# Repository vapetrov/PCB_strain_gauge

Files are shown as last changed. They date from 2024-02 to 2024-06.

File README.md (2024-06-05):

# PCB Strain Gauge

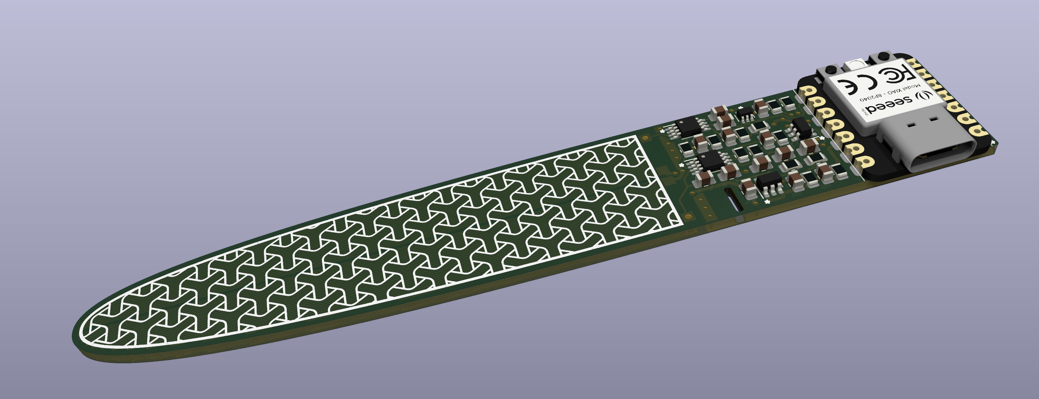
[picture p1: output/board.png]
board


A strain gauge, with amplifier, where the sensing element is the circuit board itself. Sensitive enough to measure deflections in the range of micrometers while having a full scale deflection range of +/- 3cm.

https://github.com/vapetrov/PCB_strain_gauge/assets/7529600/8c5e6594-8a19-4efe-8d25-b016dfba4ef4

### [View files with KiCanvas!](https://kicanvas.org/?github=https%3A%2F%2Fgithub.com%2Fvapetrov%2FPCB_strain_gauge)

## Manufacturing
The recommended board thickness is 0.6mm, although it could be made thicker or thinner for different applications. Thinner boards will result in a smaller output voltage swing.

- strain_gauge_3.zip
    - 20 mm x 118 mm, 2 layer
    - 0.15mm (~6mil) min trace width
    - 4-element sensing bridge
- strain_gauge_3_rotated.zip
    - Same as the previous one, except it uses 2-element sensing.
    - Lower thermal drift and bias from manufacturing (theoretically)
- stran_gauge_stiffener.zip
    - 20 mm x 42 mm rectangle to keep the component side from flexing
    - Can be affixed to the board with 3M VHB 5906

## Assembly
This project was made with hand-assembly in mind, and does not require hot air or a reflow oven.

The board can be used standalone with an integrated microcontroller (Seeed Studio XIAO RP2040) or an external microcontroller through the header pins.  
The external ADC (U5) can be omitted, and the analog voltage can be sampled directly on the "OUT" pin.  
The bias voltage generator (U8, U4) can also be omitted by placing a jumper wire between pins 2&3 on U8. Doing this will result in a measureable voltage on the output when no force is applied. 

## Programming

The included sample firmware will wait until a serial console is opened, perform a 5 second offset calibration, then sample continuously at the lowest gain setting. The `graph.py` script can be used to display the output.  
For high sensitivity measurements, it's important to let the board reach a stable operating temperature for at least 5 minutes before calibrating.

## Customatization

To customize the shape of the sensing element, `draw_footprint.ipynb` can be used to generate an outline of a given width, height and curvature. The resulting `.svg` can be imported into Inkscape and converted into a KiCad footprint using the [svg2shenzen](https://github.com/badgeek/svg2shenzhen) tool.

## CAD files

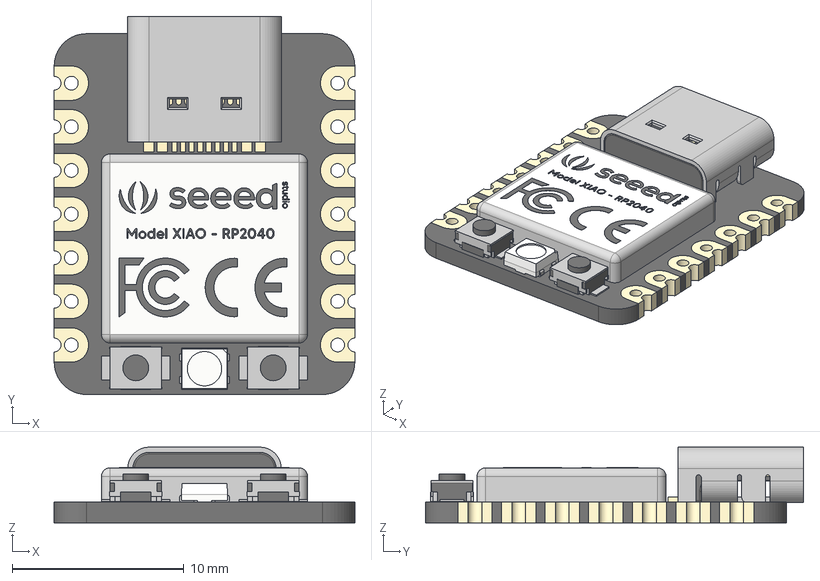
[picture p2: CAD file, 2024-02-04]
3D/Seeed Studio XIAO RP2040 v26.step
17.5 x 22.0 x 4.40 mm
type-c v2
smd_button v3
DOUT
DIN
VSS
VDD
smd_button v3(Mirror)

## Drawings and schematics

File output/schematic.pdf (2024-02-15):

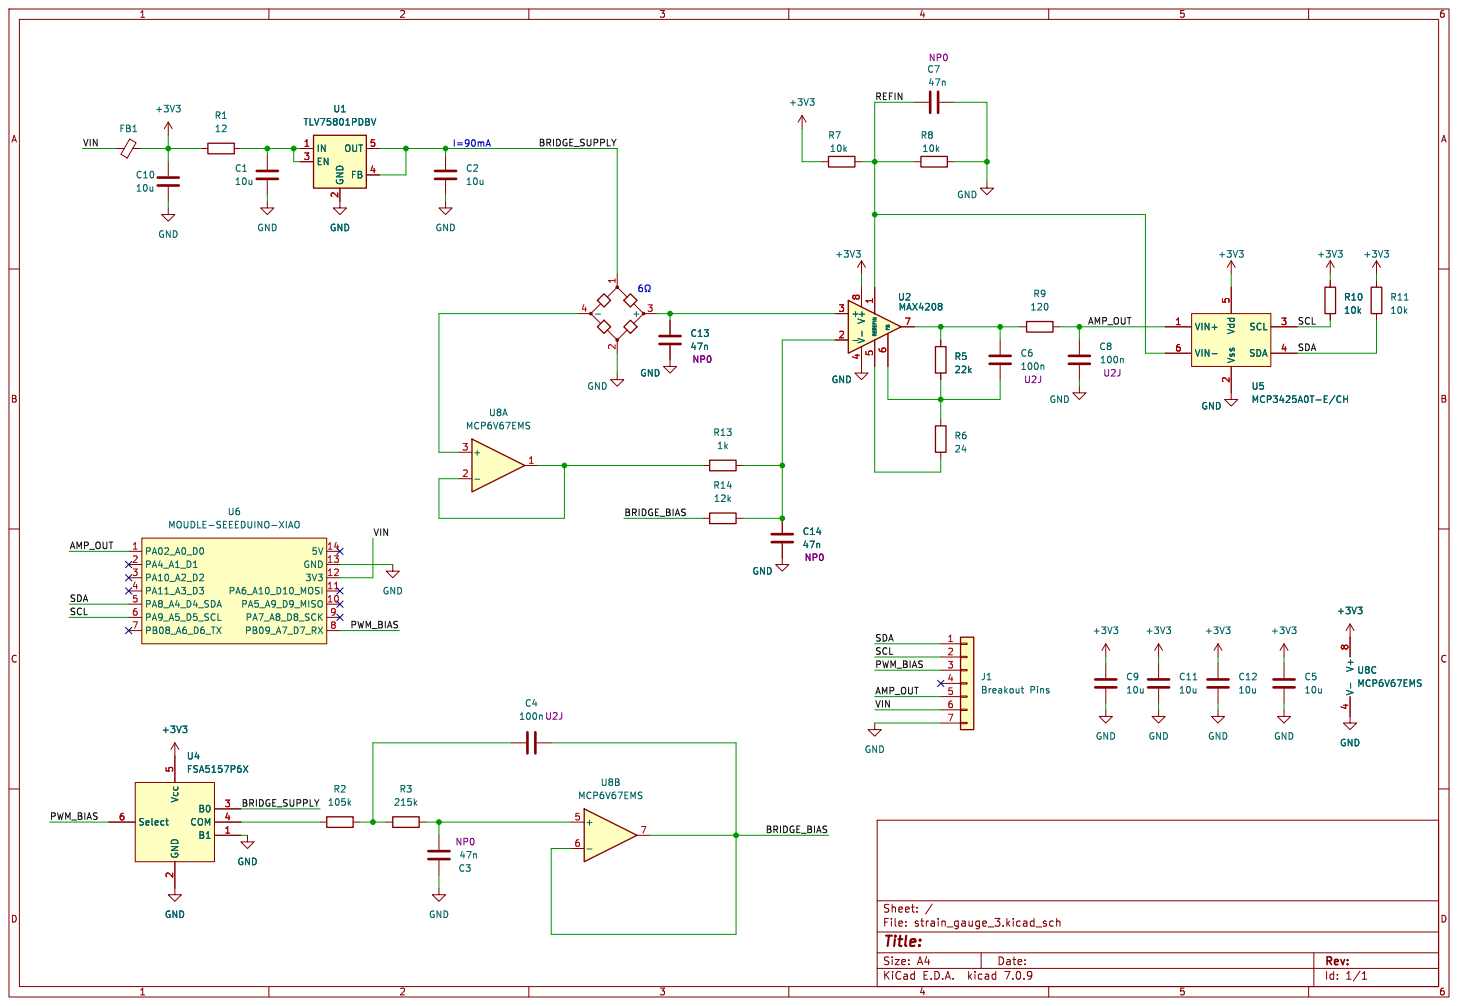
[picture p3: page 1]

2 EN 3 FB 4 OUT 5 U1 TLV75801PDBV GND

2 B0 3 COM 4 Vcc 5 Select 6 R5 GND 22k C13

Id: 1/1 Title: File: strain_gauge_3.kicad_sch Sheet: /

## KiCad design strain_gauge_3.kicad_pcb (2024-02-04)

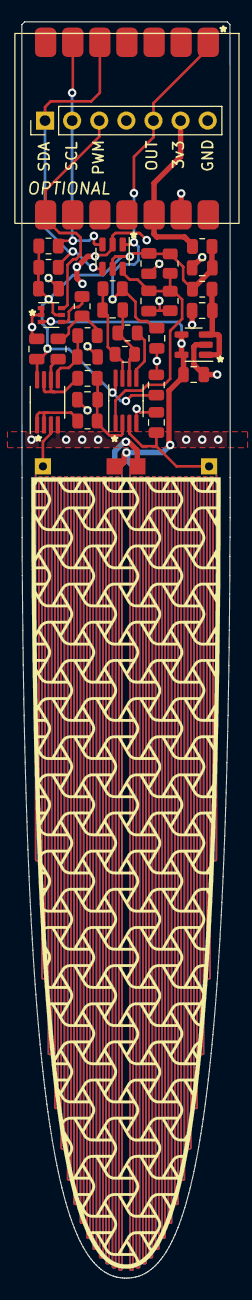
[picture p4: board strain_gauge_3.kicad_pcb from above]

Board: 2 copper layers, 19.5 x 117.7 mm, 37 parts (0 on the bottom side), 21 nets.

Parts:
C1, C2, C5, C9, C10, C11, C12: 10u; C_0805_2012Metric
C3, C7, C13, C14: 47n; C_0805_2012Metric
C4, C6, C8: 100n; C_0805_2012Metric
FB1: FerriteBead_Small; R_0805_2012Metric
J1: Breakout Pins; PinHeader_1x07_P2.54mm_Vertical
R1: 12; R_0805_2012Metric
R2: 105k; R_0805_2012Metric
R3: 215k; R_0805_2012Metric
R5: 22k; R_0805_2012Metric
R6: 24; R_0805_2012Metric
R7, R8, R10, R11: 10k; R_0805_2012Metric
R9: 120; R_0805_2012Metric
R13: 1k; R_0805_2012Metric
R14: 12k; R_0805_2012Metric
Ref**: Val**; texture
U1: TLV75801PDBV; SOT-23-5
U2: MAX4208; MSOP-8_3x3mm_P0.65mm
U4: FSA5157P6X; SOT-363_SC-70-6
U5: MCP3425A0T-E/CH; SOT-23-6
U6: MOUDLE-SEEEDUINO-XIAO; MOUDLE14P-SMD-2.54-21X17.8MM
U7: bridge
U8: MCP6V67EMS; MSOP-8_3x3mm_P0.65mm
e: slot

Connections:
+3V3: C5.1, C9.1, C10.1, C11.1, C12.1, FB1.2, R1.1, R7.2, R10.2, R11.2, U2.8 (V+), U4.5 (Vcc), U5.5 (Vdd), U8.8 (V+)
/AMP_OUT: C8.2, J1.5, R9.2, U5.1 (VIN+), U6.1 (PA02_A0_D0)
/BRIDGE_BIAS: C4.2, R14.1, U8.6 (-), U8.7
/BRIDGE_SUPPLY: C2.1, U1.4 (FB), U1.5 (OUT), U4.3 (B0), U7.1
/PWM_BIAS: J1.3, U4.6 (Select), U6.8 (PB09_A7_D7_RX)
/REFIN: C7.2, R7.1, R8.2, U2.1 (REFIN), U5.6 (VIN-)
/SCL: J1.2, R10.1, U5.3 (SCL), U6.6 (PA9_A5_D5_SCL)
/SDA: J1.1, R11.1, U5.4 (SDA), U6.5 (PA8_A4_D4_SDA)
/VIN: FB1.1, J1.6, U6.12 (3V3)
GND: C1.2, C2.2, C3.2, C5.2, C7.1, C8.1, C9.2, C10.2, C11.2, C12.2, C13.1, C14.1, J1.7, R8.1, U1.2 (GND), U2.4 (V-), U4.1 (B1), U4.2 (GND), U5.2 (Vss), U6.13 (GND), U7.2, U8.4 (V-)
unnamed: C4.1, R2.2, R3.1
unnamed: C6.1, R5.1, R9.1, U2.7
unnamed: C1.1, R1.2, U1.1 (IN), U1.3 (EN)
unnamed: C13.2, U2.3 (+), U7.3 (+)
unnamed: C14.2, R13.2, R14.2, U2.2 (-)
unnamed: C6.2, R5.2, R6.1, U2.6 (FB)
unnamed: R6.2, U2.5 (REF)
unnamed: R2.1, U4.4 (COM)
unnamed: U7.4 (-), U8.3 (+)
unnamed: R13.1, U8.1, U8.2 (-)
unnamed: C3.1, R3.2, U8.5 (+)

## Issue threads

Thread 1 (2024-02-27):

minimum layer thickness

tiralonghipol, 2024-02-27:
amazing project! thanks for open sourcing this

what would be the minimum thickness of the plate? I am looking for something like 45 / 60 degree bending, more like a flex sensor
do you think it is possible? sorry if the question might sounds dumb, my knowledge in pcd design is very minor

vapetrov, 2024-02-27:
Signal strength is proportional to thickness. In other words, if you make it half as thick you will get half the output signal (at least theoretically, it might be less than half in practice). If you do make it very thin, make sure to reinforce the area underneath the solder joins to prevent cracking.

tiralonghipol, 2024-02-27:
@vapetrov  thank you for the fast reply!
as you wrote in the readme, but just to confirm: to minimize weight I can leave out U6, U4 from the assembly and read with my own external adc on the output pins, is that correct?

vapetrov, 2024-02-27:
Yes, with some caveats. If you use your own external ADC, the zero point will be at half the supply voltage (1.65v) so your readings might shift around if the supply voltage changes. If you omit the biasing circuitry, you might end up with a large bias voltage when the sensor is at rest. It really depends on how lucky you get with the tolerances of the layer thickness from the manufacturer. They don't guarantee you will get *exactly* 1oz/35µm, and 1µ in either direction will throw off the readings entirely.

I suggest building it as-is and removing stuff one by one to see how it would affect the quality of your readings.

tiralonghipol, 2024-02-27:
thank you again, I will give it a try!

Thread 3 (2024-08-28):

BLE/Wifi connectivity Xiao

Arakistech, 2024-08-28:
Hi! Very nice project! I am interested in using a Xiao board with wireless conectivity. What it would take to implement that?

Regards

vapetrov, 2024-08-30:
There's a footprint for header pins on the board. You can solder in some wires and hook it up to whatever you want without modifying the board.

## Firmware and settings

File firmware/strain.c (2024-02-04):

#include <stdio.h>
#include <stdlib.h>
#include "pico/stdlib.h"
#include "pico/time.h"
#include "hardware/pwm.h"
#include "hardware/i2c.h"
#include "math.h"

#define ADC_ADDR 0b01101000
#define READ_SINGLE_1x 0b10001000
#define READ_SINGLE_8x 0b10001011

#define FILTER_SETTLE_MS 50
#define MAX_PWM_STEPS 4096

#define LED_G 16
#define LED_B 25
#define LED_R 17

void i2c_error(){

    printf("i2c has failed.\n");
    while(1);
}

int16_t read_adc(uint8_t config){

    uint8_t data_w = config;
    uint8_t data_r[3];
    int transfer;

    transfer = i2c_write_timeout_us(i2c1, ADC_ADDR, &data_w, 1, false, 1000 );
    if( transfer != 1 ) i2c_error();
    sleep_ms(50); // 11 < SPS < 20.5

    bool done;
    unsigned int loops = 0;
    do{
        transfer = i2c_read_timeout_us(i2c1, ADC_ADDR, data_r, 3, false, 1000); 
        if( transfer !=3 ) i2c_error();
        done = !(data_r[2]&(1<<7));
        if( !done )sleep_ms(5);
        loops++;
    }while( !done && loops <= 13);

    if( loops >= 13 ){
        i2c_error();
    }

    int16_t adc_read = __builtin_bswap16(*((int16_t*)data_r));
    return adc_read;
}



int main()
{

    stdio_init_all();
    gpio_init(2);
    gpio_set_dir(2, GPIO_OUT);
    gpio_put(2, 1);
    gpio_init(LED_R);
    gpio_init(LED_G);
    gpio_init(LED_B);
    gpio_set_dir(LED_R, GPIO_OUT);
    gpio_set_dir(LED_G, GPIO_OUT);
    gpio_set_dir(LED_B, GPIO_OUT);
    gpio_put(LED_R, 1);
    gpio_put(LED_G, 1);
    gpio_put(LED_B, 1);
    i2c_init(i2c1, 100E3);
    gpio_set_function(6, GPIO_FUNC_I2C);
    gpio_set_function(7, GPIO_FUNC_I2C);


    // wait for serial console.
    while(!stdio_usb_connected()); 
    gpio_put(LED_B, 0);
    printf("Starting...\n");


    // Find optimal PWM duty cycle with a binary search.
    // ~4000 steps is the highest we can achive while still being able to remove AC component with 2nd order LPF.

    int16_t adc_val;
    int16_t pwm_new;
    int16_t pwm_low = 0;
    int16_t pwm_high = MAX_PWM_STEPS;

    gpio_set_function(1, GPIO_FUNC_PWM);
    uint slice_num = pwm_gpio_to_slice_num(1);
    pwm_set_wrap(slice_num, pwm_high);
    pwm_set_chan_level(slice_num, PWM_CHAN_A, 0);
    pwm_set_enabled(slice_num, true);

    while( pwm_high - pwm_low > 2 ){
        pwm_new = (pwm_high+pwm_low)/2;
        pwm_set_chan_level(slice_num, PWM_CHAN_B, pwm_new);
        sleep_ms(FILTER_SETTLE_MS);
        adc_val = read_adc(READ_SINGLE_8x);
        printf("%d/%d => %d\n", pwm_new, MAX_PWM_STEPS, adc_val);

        if(adc_val < 0)pwm_low = pwm_new;
        if(adc_val > 0)pwm_high = pwm_new;
        // TODO: off my one here.
        if(abs(adc_val) < 100)break;
    }

    // step through additional PWM frequencies to find a more optimal solution.

    float target_approx = pwm_new*1.0 / (MAX_PWM_STEPS);
    const int16_t primes[] = {2011, 2153, 2333, 2467, 2659, 2789, 2953, 3121, 3307, 3463, 3613, 3769, 3929, 4099};
    int16_t optimal_pwm = 0;
    int16_t optimal_div = 0;
    int32_t lowest_adc = 99999;
    for(int i=0; i<14; i++){
        pwm_new = lrint(target_approx * primes[i]);
        int16_t pwm_lowest = pwm_new; 
        pwm_set_wrap(slice_num, primes[i]);
        pwm_set_chan_level(slice_num, PWM_CHAN_B, pwm_new);
        sleep_ms(FILTER_SETTLE_MS);
        int32_t val = 0;
        val = read_adc(READ_SINGLE_8x);
        int32_t val_lowest = val;
        int dir = val_lowest < 0 ? 1 : -1 ;
        while(1){
            pwm_new = pwm_new + dir;
            pwm_set_chan_level(slice_num, PWM_CHAN_B, pwm_new);
            sleep_ms(FILTER_SETTLE_MS);
            int32_t val = 0;
            val = read_adc(READ_SINGLE_8x);
            if(abs(val) < abs(val_lowest)){
                val_lowest = val;
                pwm_lowest = pwm_new;
            }else{
                break;
            }
        }

        if(abs(val_lowest) < abs(lowest_adc)){
            lowest_adc = val_lowest;
            optimal_pwm = pwm_lowest;
            optimal_div = primes[i];
        }
        printf("%d/%d => %ld\n",pwm_lowest, primes[i], val_lowest);
    }

    // Any remaining bias will be subtracted digitally.

    pwm_set_wrap(slice_num, optimal_div);
    pwm_set_chan_level(slice_num, PWM_CHAN_B, optimal_pwm);
    sleep_ms(FILTER_SETTLE_MS);
    int32_t bias = 0;
    for(int i=0;i<8;i++)bias = bias + read_adc(READ_SINGLE_8x);
    bias = bias/8;
    printf("Final optimization: %ld\n", bias);
    printf("============\n");
    gpio_put(LED_B, 1);

    int32_t window[32] = {0};
    uint16_t pos=0;
    while(1){

        // pick a gain level.

        //window[pos] = read_adc(READ_SINGLE_8x)-bias;
        window[pos] = read_adc(READ_SINGLE_1x)-(bias/8);

        pos = (pos+1)%32;
        gpio_put(LED_G, 1);
        if(pos%8 == 0){
            gpio_put(LED_G, 0);
            int32_t sum = 0;
            for(int i=0; i<32; i++){
                sum = sum+window[i];
            }
            sum = sum/32;
            printf("%ld\n",sum);
        }
    }


}

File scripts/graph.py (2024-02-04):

"""
Various methods of drawing scrolling plots.
"""

from time import perf_counter

import numpy as np
import serial
import pyqtgraph as pg

import serial.tools.list_ports
s = serial.Serial("COM17", 0, timeout=1)

print(pg.__version__)

pg.setConfigOptions(useOpenGL=True, antialias=True)
#pg.setConfigOptions(antialias=True)

win = pg.GraphicsLayoutWidget(show=True)
win.setWindowTitle('pyqtgraph example: Scrolling Plots')


# 1) Simplest approach -- update data in the array such that plot appears to scroll
#    In these examples, the array size is fixed.
p2 = win.addPlot()
p2.setYRange(-25E3, 25E3, padding=0)
data1 = np.zeros(600)
p2.showGrid(x = True, y = True, alpha = 1.0)
curve2 = p2.plot(data1, pen=pg.mkPen((1.2,250,0), width=4), skipFiniteCheck=True)
ptr1 = 0
def update1():
    global data1, ptr1
    data1[:-1] = data1[1:]  # shift data in the array one sample left
                            # (see also: np.roll)
    #data1[-1] = s.readline().decode("utf-8").split("*")[1]
    try:    
        data1[-1] = int(s.readline().decode("utf-8"))
    except:
        pass

    
    ptr1 += 1
    curve2.setData(data1, skipFiniteCheck=True)
    curve2.setPos(ptr1, 0)
    #print(s.readline().decode("utf-8").split("*")[1])
    

timer = pg.QtCore.QTimer()
timer.timeout.connect(update1)

s.read(s.in_waiting)
timer.start(1)


if __name__ == '__main__':
    pg.exec()

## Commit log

2024-02-04 initial commit.
    [Seeed Studio XIAO RP2040 v26.step, strain_gauge_3.kicad_pcb, strain_gauge_3.kicad_sch]
2024-02-15 added schematic pdf
